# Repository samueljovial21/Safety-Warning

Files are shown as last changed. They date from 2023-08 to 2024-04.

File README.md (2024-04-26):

# Safety-Warning

## Final Project as a bachelor degree of Informatics Engineer

Various problems arise in the use of motorcycles. Among the common issues are the
high occurrence of traffic accidents at high speeds and motorcycle theft. Traffic
accidents generally happen due to users not adhering to safe speed limits, especially
in urban areas, while motorcycle theft is prevalent due to the minimal security
measures in place. <br/> <br/>
Therefore, the aim of this research is to develop an integrated
hardware and software system capable of minimizing these issues using Fuzzy logic
methods followed by experimental field testing. The hardware system is constructed
using several electronic components such as sensors and actuators. <br/> <br/>
The sensors used include GPS Ublox neo 6m, mpu6050, and sw420, while the actuators consist of a high
decibel buzzer, LED, and relay module. Other components such as the LM2596 step-
down DC module, SIM800L module, capacitors, and resistors are also utilized in the
circuitry process. <br/> <br/>
For software development, Arduino IDE is used as the platform for
microcontroller script development, and MIT App Inventor is employed for designing
the mobile application interface. <br/> <br/>
The system is broadly divided into two modes: driving
mode and parking mode. In driving mode, users are alerted about speed limits and the
maximum tilt angle while turning. In parking mode, the system secures the
motorcycle's electrical path using a relay and detects indications of theft using sensors. <br/> <br/>
The results of this research include the design of a hardware and software system in
the form of a circuit that has been experimentally tested in the field. The implemented
design was then tested for accuracy of sensor readings and the compatibility of sensor
and actuator performance in following the specified logic commands. <br/> <br/>
The accuracy testing of the sensors yielded values above 70%, and the actuators successfully
executed actions according to the embedded logic in the microcontroller. Therefore,
the developed and tested system can be deemed to work according to the
predetermined design.

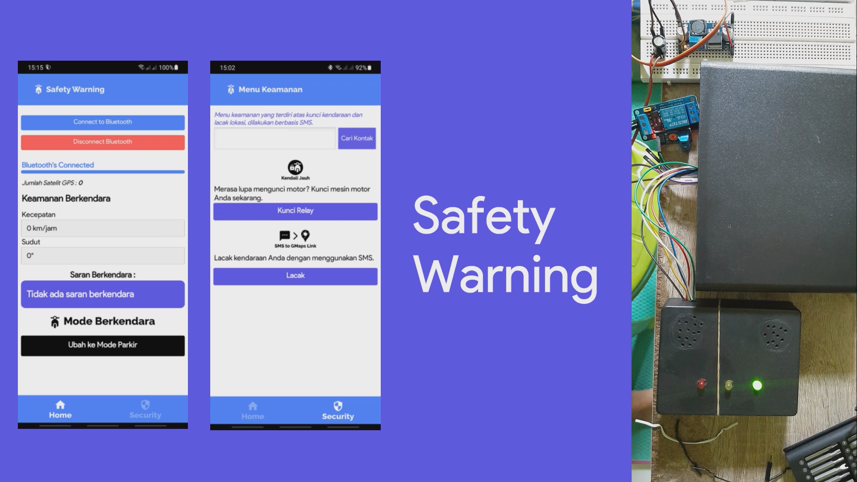
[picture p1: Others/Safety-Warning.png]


## Testing Video
Click here : [Video Link](https://youtu.be/pdXKAxoBCNw).

## Components Needed
* ESP32 Development Board (1) <br/>
* PCB (2) <br/>
* Box (2) <br/>
* LM2596 DC Stepdown Modul (2) <br/>
* GPS Ublox Neo 6m (1) <br/>
* SIM800L Module (1) <br/>
* SW420 Vibration Sensor (1) <br/>
* MPU6050 Gyroscope Sensor (1) <br/>
* Relay Module 1 Channel (1) <br/>
* 470uF 16V Capasitor (1) <br/>
* 470uF 25V Capasitor (1) <br/>
* High Decibel Buzzer (2) <br/>
* LED (Red (1), Yellow(1), Green(1)) <br/>
* 220 ohm Resistor (3) <br/>

## Wiring Diagram

### Wiring on board (PCB) <br/>
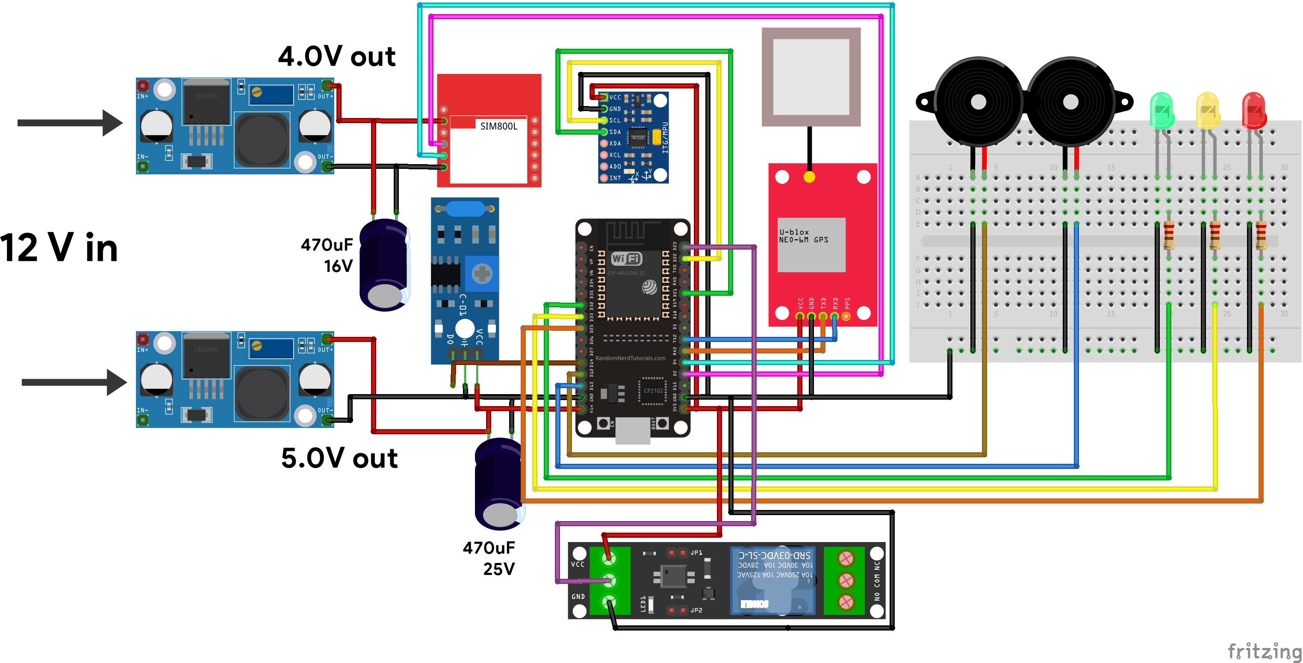
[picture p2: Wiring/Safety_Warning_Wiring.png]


### Wiring on Relay to Motorcycle Battery <br/>
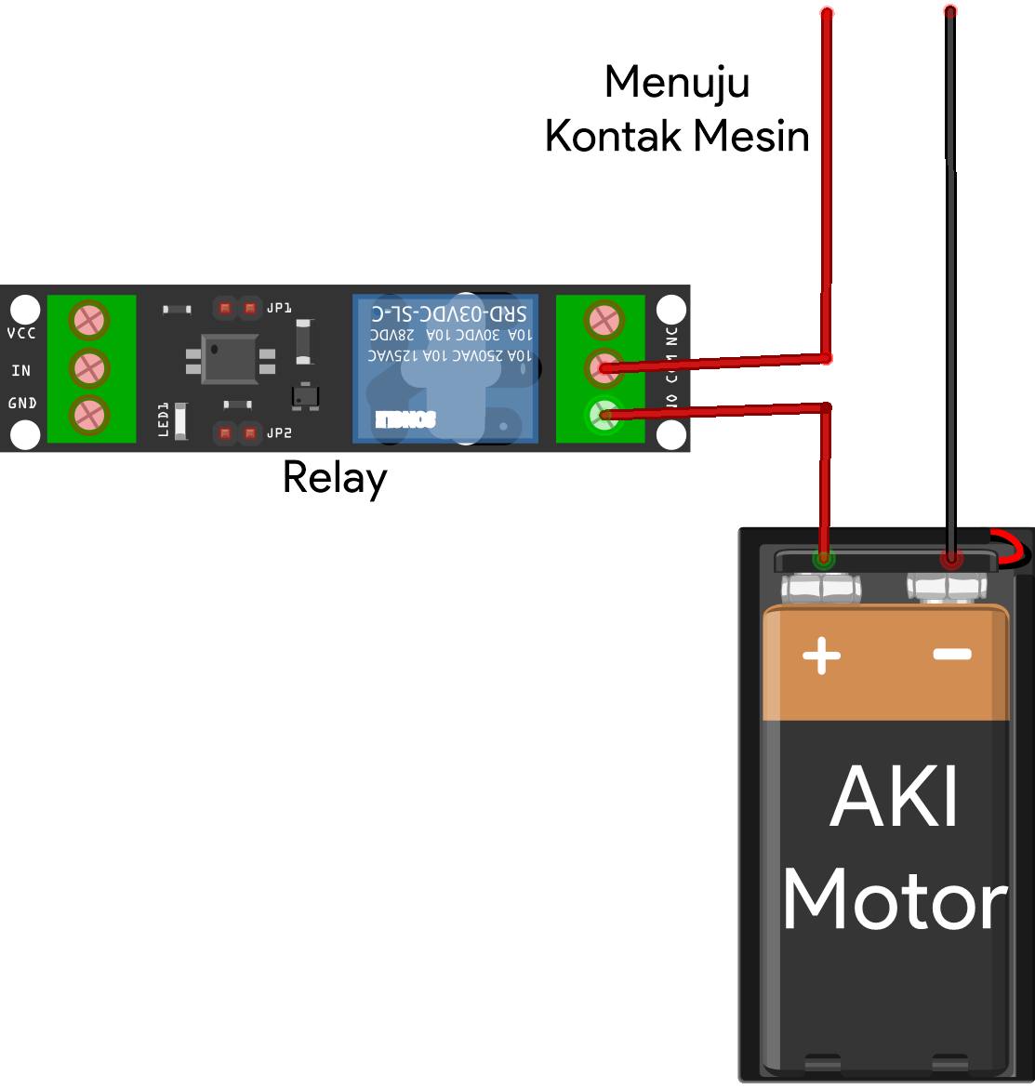
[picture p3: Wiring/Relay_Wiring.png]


## Others <br/>
### Main Box Design <br/>
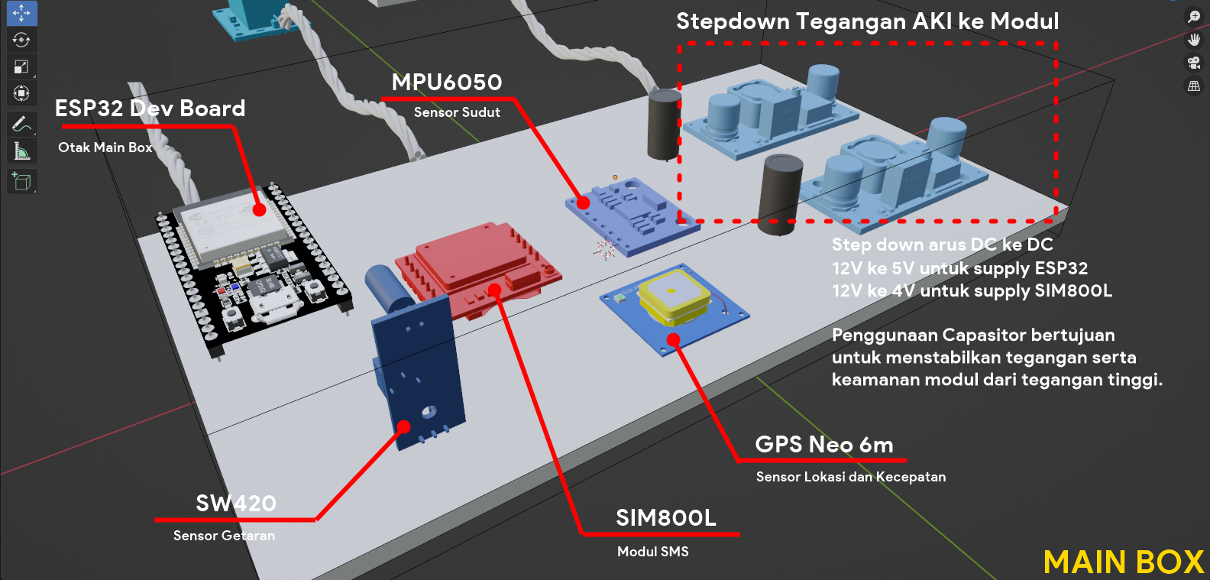
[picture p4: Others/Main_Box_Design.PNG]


### Actuator Box Design <br/>
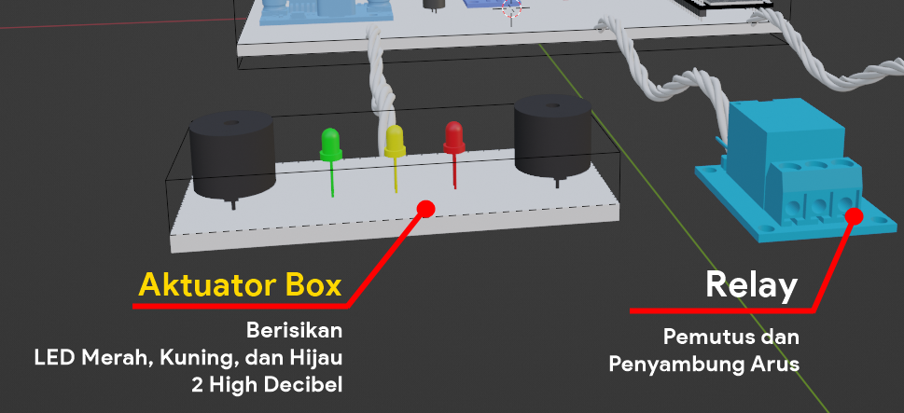
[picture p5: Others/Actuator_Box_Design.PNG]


### Implementation Design <br/>
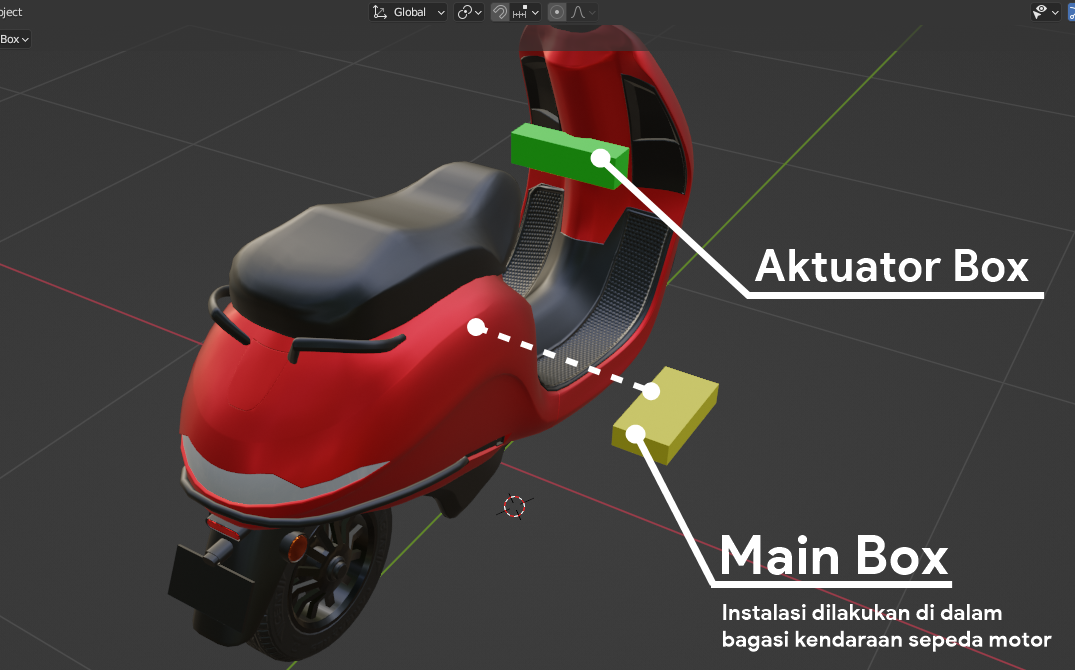
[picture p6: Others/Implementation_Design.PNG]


### MIT App Inventor <br/>
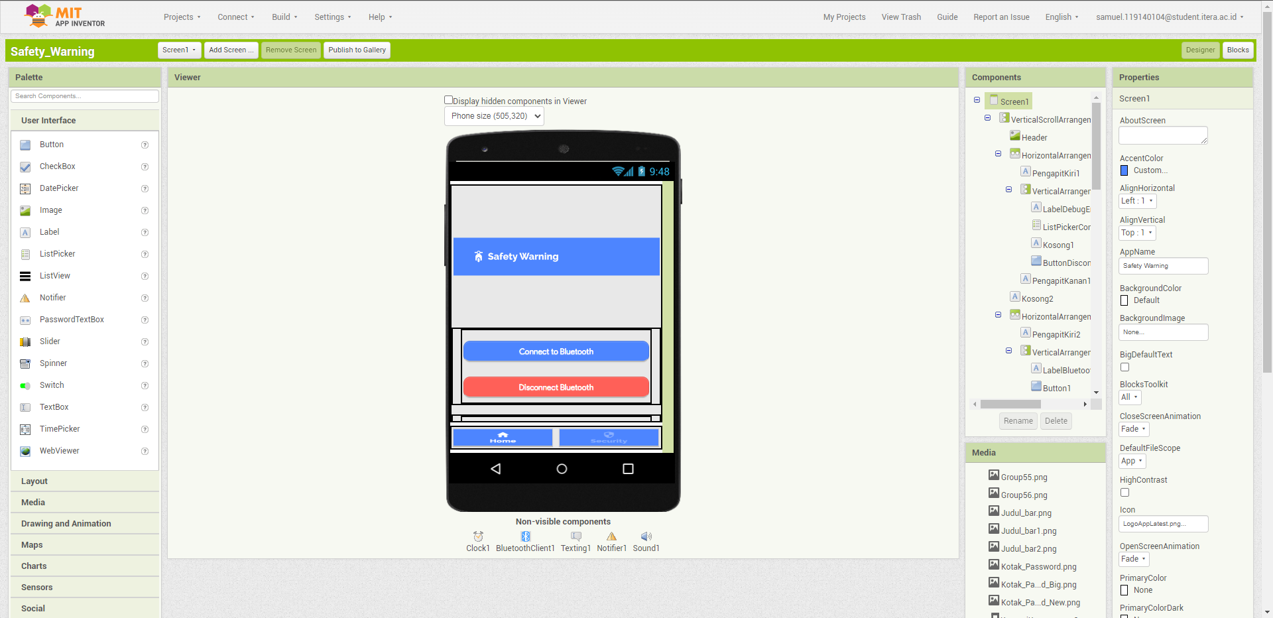
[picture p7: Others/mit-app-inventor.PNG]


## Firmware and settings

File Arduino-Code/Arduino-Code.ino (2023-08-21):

// Library and Init Section
// this header is needed for Bluetooth Serial -> works ONLY on ESP32
#include "BluetoothSerial.h"

// init Class:
#if !defined(CONFIG_BT_ENABLED) || !defined(CONFIG_BLUEDROID_ENABLED)
#error Bluetooth is not enabled! Please run `make menuconfig` to and enable it
#endif

BluetoothSerial SerialBT;

int incoming;
int button;
int value;

#include <MPU6050_tockn.h>
#include <Wire.h>
#include <TinyGPS++.h>
#include <SoftwareSerial.h>
TinyGPSPlus gps;
SoftwareSerial serial_gps(16, 17);  //TX and RX
double latitude, longitude;

#define LedRed 25
#define LedYellow 33
#define LedGreen 32

#define ANALOG_IN_PIN 27
#define RELAY 23

#define buzzer1 12
#define buzzer2 13

#define getar 14

#define rxPin 4
#define txPin 2
HardwareSerial sim800(1);


MPU6050 mpu6050(Wire);
int sudut;

long timer = 0;

String pesan;

int present_condition = 0;
int previous_condition = 0;

bool getaran = false;

int kecepatan;

bool mode = true;  // True for riding mode & false for parking mode

String saran;
int hasil = 0;

int satelit = 0;

// Millis
unsigned long interval = 1000;     // the time we need to wait
unsigned long previousMillis = 0;  // millis() returns an unsigned long.

// State Aktuator
bool buzz1State = false;
bool buzz2State = false;

bool redState = false;
bool yellowState = false;
bool greenState = false;

void setup() {
  Serial.begin(115200);

  SerialBT.begin("ESPSafetyWarning");  //Name of your Bluetooth interface -> will show up on your phone
  Serial.println("The device started, now you can pair with bluetooth!");

  pinMode(LedRed, OUTPUT);
  pinMode(LedYellow, OUTPUT);
  pinMode(LedGreen, OUTPUT);

  pinMode(RELAY, OUTPUT);

  pinMode(buzzer1, OUTPUT);
  pinMode(buzzer2, OUTPUT);

  pinMode(getar, INPUT);

  digitalWrite(RELAY, LOW);

  pesan = "";

  Wire.begin();
  mpu6050.begin();
  mpu6050.calcGyroOffsets(true);

  serial_gps.begin(9600);

  //Begin serial communication with Arduino and SIM800L
  sim800.begin(9600, SERIAL_8N1, rxPin, txPin);

  sim800.println("AT+CMGF=1");  // Configuring TEXT mode
  delay(1000);
  sim800.println("AT+CSQ");
  delay(1000);
  sim800.println("AT+CNMI=1,2,0,0,0");
  delay(1000);
}

void loop() {
  // Read The Incoming Bluetooth Value
  if (SerialBT.available()) {
    incoming = SerialBT.read();

    button = floor(incoming / 10);
    value = incoming % 10;
  }

  if (button == 1) {
    if (value == 1) {
      mode = true;
    } else {
      mode = false;
    }
  }

  saran = "Tidak ada saran berkendara";

  // Getting Value of Y Axis Gyro
  getSudut();

  // Getting Value of GPS
  boolean newData = false;
  for (unsigned long start = millis(); millis() - start < 250;) {
    while (serial_gps.available()) {
      if (gps.encode(serial_gps.read())) {
        newData = true;
      }
    }
  }

  // Getting Value of Speed from GPS
  if (newData == true) {
    newData = false;
    if (gps.satellites.value() != 0) {
      kecepatan = gps.speed.kmph();
      satelit = gps.satellites.value();
    }
  }

  // Read The Sim800l serial
  if (Serial.available()) {
    sim800.write(Serial.read());
  }

  // Read incoming message
  if (sim800.available() > 0) {
    pesan = sim800.readStringUntil('\n');
    pesan.toLowerCase();
    Serial.println(pesan);
    // calling function if the message is "get location"
    if (pesan == "get location\r") {
      getLink();
      // calling function if the message is "relay off"
    } else if (pesan == "relay off\r") {
      mode = false;
      notifikasi();
    }
  }

  // Cek Getaran
  previous_condition = present_condition;
  present_condition = digitalRead(getar);
  if (previous_condition != present_condition) {
    getaran = true;
  } else {
    getaran = false;
  }

  unsigned long currentMillis = millis();  // grab current time

  
  // Mode Safety
  if (mode) {  // Mode Berkendara
    digitalWrite(RELAY, HIGH);
    // Logika Kecepatan

    // Logic Batas Kecepatan
    if ((kecepatan >= 50) && (kecepatan < 70)) {
      saran = "Kurangi kecepatan Anda";
      if (!buzz1State) {
        interval = 4000;
      } else {
        interval = 1000;
      }

      if ((unsigned long)(currentMillis - previousMillis) >= interval) {

        buzz1State = !buzz1State;
        digitalWrite(buzzer1, buzz1State);
        // save the "current" time
        previousMillis = millis();
      }
    } else if ((kecepatan >= 70) && (kecepatan < 100)) {
      saran = "Anda berada di kecepatan berbahaya";
      if (!buzz1State) {
        interval = 1000;
      } else {
        interval = 1000;
      }

      if ((unsigned long)(currentMillis - previousMillis) >= interval) {

        buzz1State = !buzz1State;
        digitalWrite(buzzer1, buzz1State);
        // save the "current" time
        previousMillis = millis();
      }
    } else {
      digitalWrite(buzzer1, false);
    }

    // Peringatan Kecepatan dan Sudut
    if ((kecepatan >= 30) && (kecepatan < 50)) {
      if ((sudut >= 30) && (sudut < 35)) {
        hasil = sudut - 29;
        saran = "Anda berkendara terlalu miring sebesar " + String(hasil) + "°";
        digitalWrite(LedRed, LOW);
        digitalWrite(LedYellow, HIGH);
        digitalWrite(LedGreen, LOW);
        if (!buzz2State) {
          interval = 1000;
        } else {
          interval = 1000;
        }

        if ((unsigned long)(currentMillis - previousMillis) >= interval) {

          buzz2State = !buzz2State;
          digitalWrite(buzzer2, buzz2State);
          // save the "current" time
          previousMillis = millis();
        }
      } else if (sudut < 30) {
        digitalWrite(LedRed, LOW);
        digitalWrite(LedYellow, LOW);
        digitalWrite(LedGreen, HIGH);
        digitalWrite(buzzer2, false);
      } else if (sudut >= 35) {
        hasil = sudut - 29;
        saran = "Anda berkendara terlalu miring sebesar " + String(hasil) + "°";
        digitalWrite(LedRed, HIGH);
        digitalWrite(LedYellow, LOW);
        digitalWrite(LedGreen, LOW);
        if (!buzz2State) {
          interval = 500;
        } else {
          interval = 500;
        }

        if ((unsigned long)(currentMillis - previousMillis) >= interval) {

          buzz2State = !buzz2State;
          digitalWrite(buzzer2, buzz2State);
          // save the "current" time
          previousMillis = millis();
        }
      }
    } else if ((kecepatan >= 50) && (kecepatan < 70)) {
      if ((sudut >= 45) && (sudut < 50)) {
        hasil = sudut - 44;
        saran = "Anda berkendara terlalu miring sebesar " + String(hasil) + "°";
        digitalWrite(LedRed, LOW);
        digitalWrite(LedYellow, HIGH);
        digitalWrite(LedGreen, LOW);
        if (!buzz2State) {
          interval = 1000;
        } else {
          interval = 1000;
        }

        if ((unsigned long)(currentMillis - previousMillis) >= interval) {

          buzz2State = !buzz2State;
          digitalWrite(buzzer2, buzz2State);
          // save the "current" time
          previousMillis = millis();
        }
      } else if (sudut < 45) {
        digitalWrite(LedRed, LOW);
        digitalWrite(LedYellow, LOW);
        digitalWrite(LedGreen, HIGH);
        digitalWrite(buzzer2, false);
      } else if (sudut >= 50) {
        hasil = sudut - 44;
        saran = "Anda berkendara terlalu miring sebesar " + String(hasil) + "°";
        digitalWrite(LedRed, HIGH);
        digitalWrite(LedYellow, LOW);
        digitalWrite(LedGreen, LOW);
        if (!buzz2State) {
          interval = 500;
        } else {
          interval = 500;
        }

        if ((unsigned long)(currentMillis - previousMillis) >= interval) {

          buzz2State = !buzz2State;
          digitalWrite(buzzer2, buzz2State);
          // save the "current" time
          previousMillis = millis();
        }
      }
    } else if ((kecepatan >= 60) && (kecepatan < 70)) {
      if ((sudut >= 50) && (sudut < 55)) {
        hasil = sudut - 49;
        saran = "Anda berkendara terlalu miring sebesar " + String(hasil) + "°";
        digitalWrite(LedRed, LOW);
        digitalWrite(LedYellow, HIGH);
        digitalWrite(LedGreen, LOW);
        if (!buzz2State) {
          interval = 1000;
        } else {
          interval = 1000;
        }

        if ((unsigned long)(currentMillis - previousMillis) >= interval) {

          buzz2State = !buzz2State;
          digitalWrite(buzzer2, buzz2State);
          // save the "current" time
          previousMillis = millis();
        }
      } else if (sudut < 50) {
        digitalWrite(LedRed, LOW);
        digitalWrite(LedYellow, LOW);
        digitalWrite(LedGreen, HIGH);
        digitalWrite(buzzer2, false);
      } else if (sudut >= 55) {
        hasil = sudut - 49;
        saran = "Anda berkendara terlalu miring sebesar " + String(hasil) + "°";
        digitalWrite(LedRed, HIGH);
        digitalWrite(LedYellow, LOW);
        digitalWrite(LedGreen, LOW);
        if (!buzz2State) {
          interval = 500;
        } else {
          interval = 500;
        }

        if ((unsigned long)(currentMillis - previousMillis) >= interval) {

          buzz2State = !buzz2State;
          digitalWrite(buzzer2, buzz2State);
          // save the "current" time
          previousMillis = millis();
        }
      }
    } else if ((kecepatan >= 70) && (kecepatan < 80)) {
      if ((sudut >= 60) && (sudut < 65)) {
        hasil = sudut - 59;
        saran = "Anda berkendara terlalu miring sebesar " + String(hasil) + "°";
        digitalWrite(LedRed, LOW);
        digitalWrite(LedYellow, HIGH);
        digitalWrite(LedGreen, LOW);
        if (!buzz2State) {
          interval = 1000;
        } else {
          interval = 1000;
        }

        if ((unsigned long)(currentMillis - previousMillis) >= interval) {

          buzz2State = !buzz2State;
          digitalWrite(buzzer2, buzz2State);
          // save the "current" time
          previousMillis = millis();
        }
      } else if (sudut < 60) {
        digitalWrite(LedRed, LOW);
        digitalWrite(LedYellow, LOW);
        digitalWrite(LedGreen, HIGH);
        digitalWrite(buzzer2, false);
      } else if (sudut >= 65) {
        hasil = sudut - 59;
        saran = "Anda berkendara terlalu miring sebesar " + String(hasil) + "°";
        digitalWrite(LedRed, HIGH);
        digitalWrite(LedYellow, LOW);
        digitalWrite(LedGreen, LOW);
        if (!buzz2State) {
          interval = 500;
        } else {
          interval = 500;
        }

        if ((unsigned long)(currentMillis - previousMillis) >= interval) {

          buzz2State = !buzz2State;
          digitalWrite(buzzer2, buzz2State);
          // save the "current" time
          previousMillis = millis();
        }
      }
    } else if ((kecepatan >= 80) && (kecepatan < 90)) {
      if ((sudut >= 70) && (sudut < 75)) {
        hasil = sudut - 69;
        saran = "Anda berkendara terlalu miring sebesar " + String(hasil) + "°";
        digitalWrite(LedRed, LOW);
        digitalWrite(LedYellow, HIGH);
        digitalWrite(LedGreen, LOW);
        if (!buzz2State) {
          interval = 1000;
        } else {
          interval = 1000;
        }

        if ((unsigned long)(currentMillis - previousMillis) >= interval) {

          buzz2State = !buzz2State;
          digitalWrite(buzzer2, buzz2State);
          // save the "current" time
          previousMillis = millis();
        }
      } else if (sudut < 70) {
        digitalWrite(LedRed, LOW);
        digitalWrite(LedYellow, LOW);
        digitalWrite(LedGreen, HIGH);
        digitalWrite(buzzer2, false);
      } else if (sudut >= 75) {
        hasil = sudut - 69;
        saran = "Anda berkendara terlalu miring sebesar " + String(hasil) + "°";
        digitalWrite(LedRed, HIGH);
        digitalWrite(LedYellow, LOW);
        digitalWrite(LedGreen, LOW);
        if (!buzz2State) {
          interval = 500;
        } else {
          interval = 500;
        }

        if ((unsigned long)(currentMillis - previousMillis) >= interval) {

          buzz2State = !buzz2State;
          digitalWrite(buzzer2, buzz2State);
          // save the "current" time
          previousMillis = millis();
        }
      }
    } else {
      digitalWrite(buzzer2, false);
      digitalWrite(LedGreen, HIGH);
      digitalWrite(LedRed, LOW);
      digitalWrite(LedYellow, LOW);
    }
  } else {  // Mode Parkir
    digitalWrite(RELAY, LOW);

    // Kasus 4
    if ((getaran) && (kecepatan >= 2)) {
      positipMaling();
      getLink();
      digitalWrite(LedRed, HIGH);
      digitalWrite(LedYellow, LOW);
      digitalWrite(LedGreen, LOW);
      if ((!buzz2State) || (!buzz1State)) {
        interval = 500;
      } else {
        interval = 500;
      }

      if ((unsigned long)(currentMillis - previousMillis) >= interval) {

        buzz2State = !buzz2State;
        buzz1State = !buzz1State;
        digitalWrite(buzzer2, buzz2State);
        digitalWrite(buzzer1, buzz1State);
        // save the "current" time
        previousMillis = millis();
      }
    }

    // Kasus 3
    if ((getaran) && (kecepatan < 2)) {
      digitalWrite(LedRed, LOW);
      digitalWrite(LedYellow, LOW);
      digitalWrite(LedGreen, LOW);
      if ((!buzz2State) || (!buzz1State)) {
        interval = 1000;
      } else {
        interval = 1000;
      }

      if ((unsigned long)(currentMillis - previousMillis) >= interval) {

        buzz2State = !buzz2State;
        buzz1State = !buzz1State;
        digitalWrite(buzzer2, buzz2State);
        digitalWrite(buzzer1, buzz1State);
        // save the "current" time
        previousMillis = millis();
      }
    }

    // Kasus 2
    if ((!getaran) && (kecepatan >= 2)) {
      digitalWrite(LedRed, LOW);
      digitalWrite(LedYellow, LOW);
      digitalWrite(LedGreen, LOW);
      if ((!buzz2State) || (!buzz1State)) {
        interval = 500;
      } else {
        interval = 500;
      }

      if ((unsigned long)(currentMillis - previousMillis) >= interval) {

        buzz2State = !buzz2State;
        buzz1State = !buzz1State;
        digitalWrite(buzzer2, buzz2State);
        digitalWrite(buzzer1, buzz1State);
        // save the "current" time
        previousMillis = millis();
      }
    }

    // Kasus 1
    if ((!getaran) && (kecepatan < 2)) {
      digitalWrite(LedRed, LOW);
      digitalWrite(LedYellow, LOW);
      digitalWrite(LedGreen, LOW);
      digitalWrite(buzzer2, LOW);
      digitalWrite(buzzer1, LOW);
    }
  }

  String statusGetaran;
  if (getaran) {
    statusGetaran = "Ada Getaran";
  } else {
    statusGetaran = "Tidak ada Getaran";
  }

  String nyala = "Mode Parkir Menyala";

  // Sending value to bluetooth
  if (mode) {
    SerialBT.print(String(satelit) + "-" + String(kecepatan) + " km/jam" + "-" + String(sudut) + "°" + "-" + saran);
  } else {
    if (getaran) {
      SerialBT.print(String(satelit) + "-" + "Diputus" + "-" + statusGetaran + "-" + " ");
      // delay(5000);
    } else {
      SerialBT.print(String(satelit) + "-" + "Diputus" + "-" + statusGetaran + "-" + " ");
    }
  }
}

// Getting google maps link to send via sms
void getLink() {
  boolean newData = false;
  for (unsigned long start = millis(); millis() - start < 2000;) {
    while (serial_gps.available()) {
      if (gps.encode(serial_gps.read())) {
        newData = true;
      }
    }
  }

  if (newData) {
    Serial.print(gps.location.lat(), 6);
    Serial.println(gps.location.lng(), 6);
    delay(300);

    sim800.print("AT+CMGF=1\r");
    delay(1000);
    sim800.print("AT+CMGS=\"+62xxxxxxxxxxx\"\r");
    delay(1000);
    sim800.print("http://maps.google.com/maps?q=loc:");
    sim800.print(gps.location.lat(), 6);
    sim800.print(",");
    sim800.print(gps.location.lng(), 6);
    delay(100);
    sim800.write(0x1A);  //ascii code for ctrl-26 //sim800.println((char)26); //ascii code for ctrl-26
    delay(1000);
    newData = false;
  }

  else {
    // if gps is not getting any signal
    sim800.println("AT+CMGF=1");
    delay(1000);
    sim800.println("AT+CMGS=\"+62xxxxxxxxxxx\"\r");
    delay(1000);
    sim800.print("Belum ada link");
    delay(100);
    sim800.println((char)26);
    delay(1000);
  }
}

// Change mode to parkir using sms
void notifikasi() {
  sim800.println("AT+CMGF=1");
  delay(1000);
  sim800.println("AT+CMGS=\"+62xxxxxxxxxxx\"\r");
  delay(1000);
  sim800.print("Kendaraan Anda sekarang berhasil diubah ke mode parkir.");
  delay(100);
  sim800.println((char)26);
  delay(1000);
}

// Notify the user 
void positipMaling() {
  sim800.println("AT+CMGF=1");
  delay(1000);
  sim800.println("AT+CMGS=\"+62xxxxxxxxxxx\"\r");
  delay(1000);
  sim800.println("Terindikasi Pencurian!!!");
  delay(100);
  sim800.println((char)26);
  delay(1000);
}

// Getting gyro Y axis value
void getSudut() {
  mpu6050.update();
  if (millis() - timer > 10) {
    sudut = mpu6050.getAngleY();
    if (sudut < 0) {
      sudut *= -1;
      sudut -= 4;
    }
    timer = millis();
  }
}
